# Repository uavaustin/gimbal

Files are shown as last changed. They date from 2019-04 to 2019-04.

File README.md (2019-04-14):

# gimbal
Hardware and software for UAV Austin's homebrew gimbal.

Notes:
 - MPU two jst connectors align with 7 pin header connected to STM
   - SPI connections
 - Voltage Rgulator rated for 12-13V input. Outputs 3.3V up to 250 mA
 - CP2102 USB to UART converter
 - Boot0 and Boot1 in 3 and 4 pin arrangement for programming settings
   - Boot0 connects to either ground or PWR (3.3V)
   - Boot1  (PB2) connects to ground, PWR, or the motor controller
 - MPU goes on its own board seperate from the STM, DRV, CP2102, USB, and Voltage Regulator
 - Jumper to connect NRST to ground or external input voltage
 - PA13/14 jtag | PB4/5/6/7 SPI on STM
 - 2 sets of 2 header pins to get power from battery

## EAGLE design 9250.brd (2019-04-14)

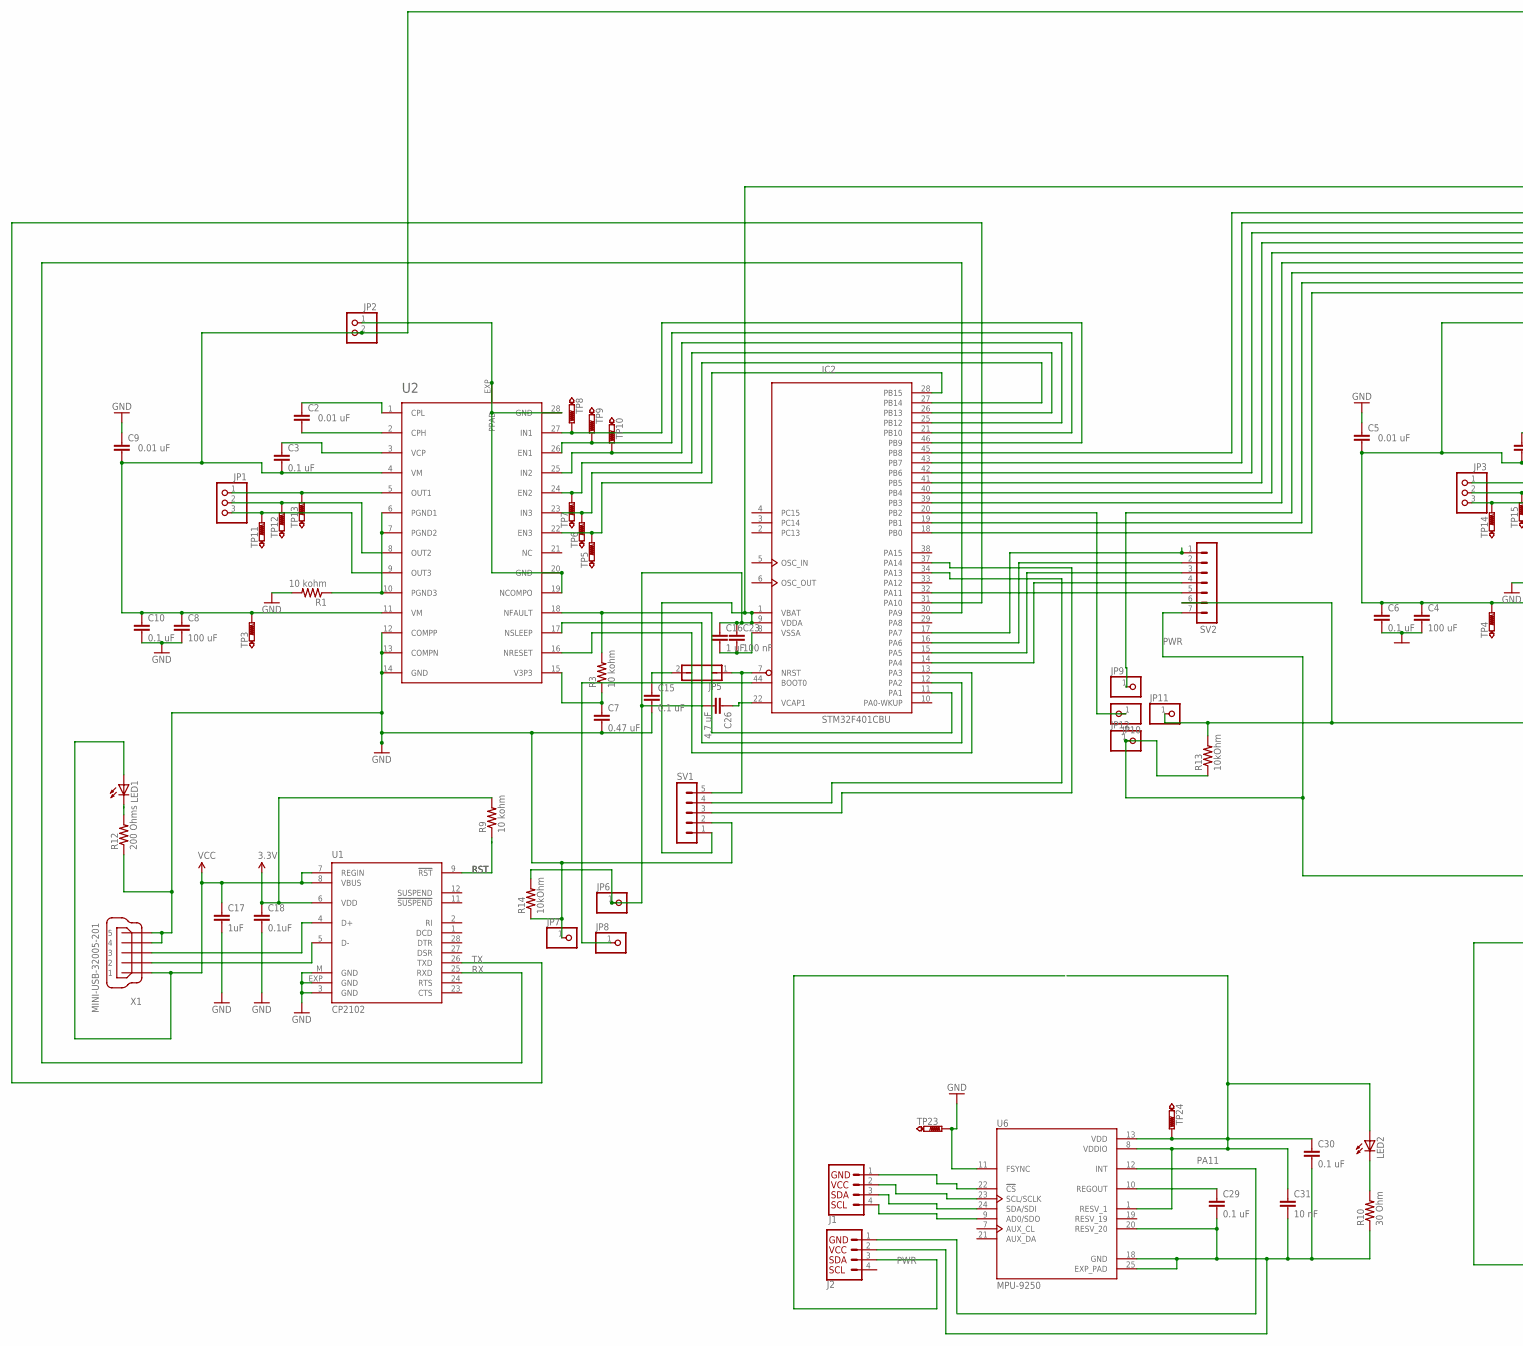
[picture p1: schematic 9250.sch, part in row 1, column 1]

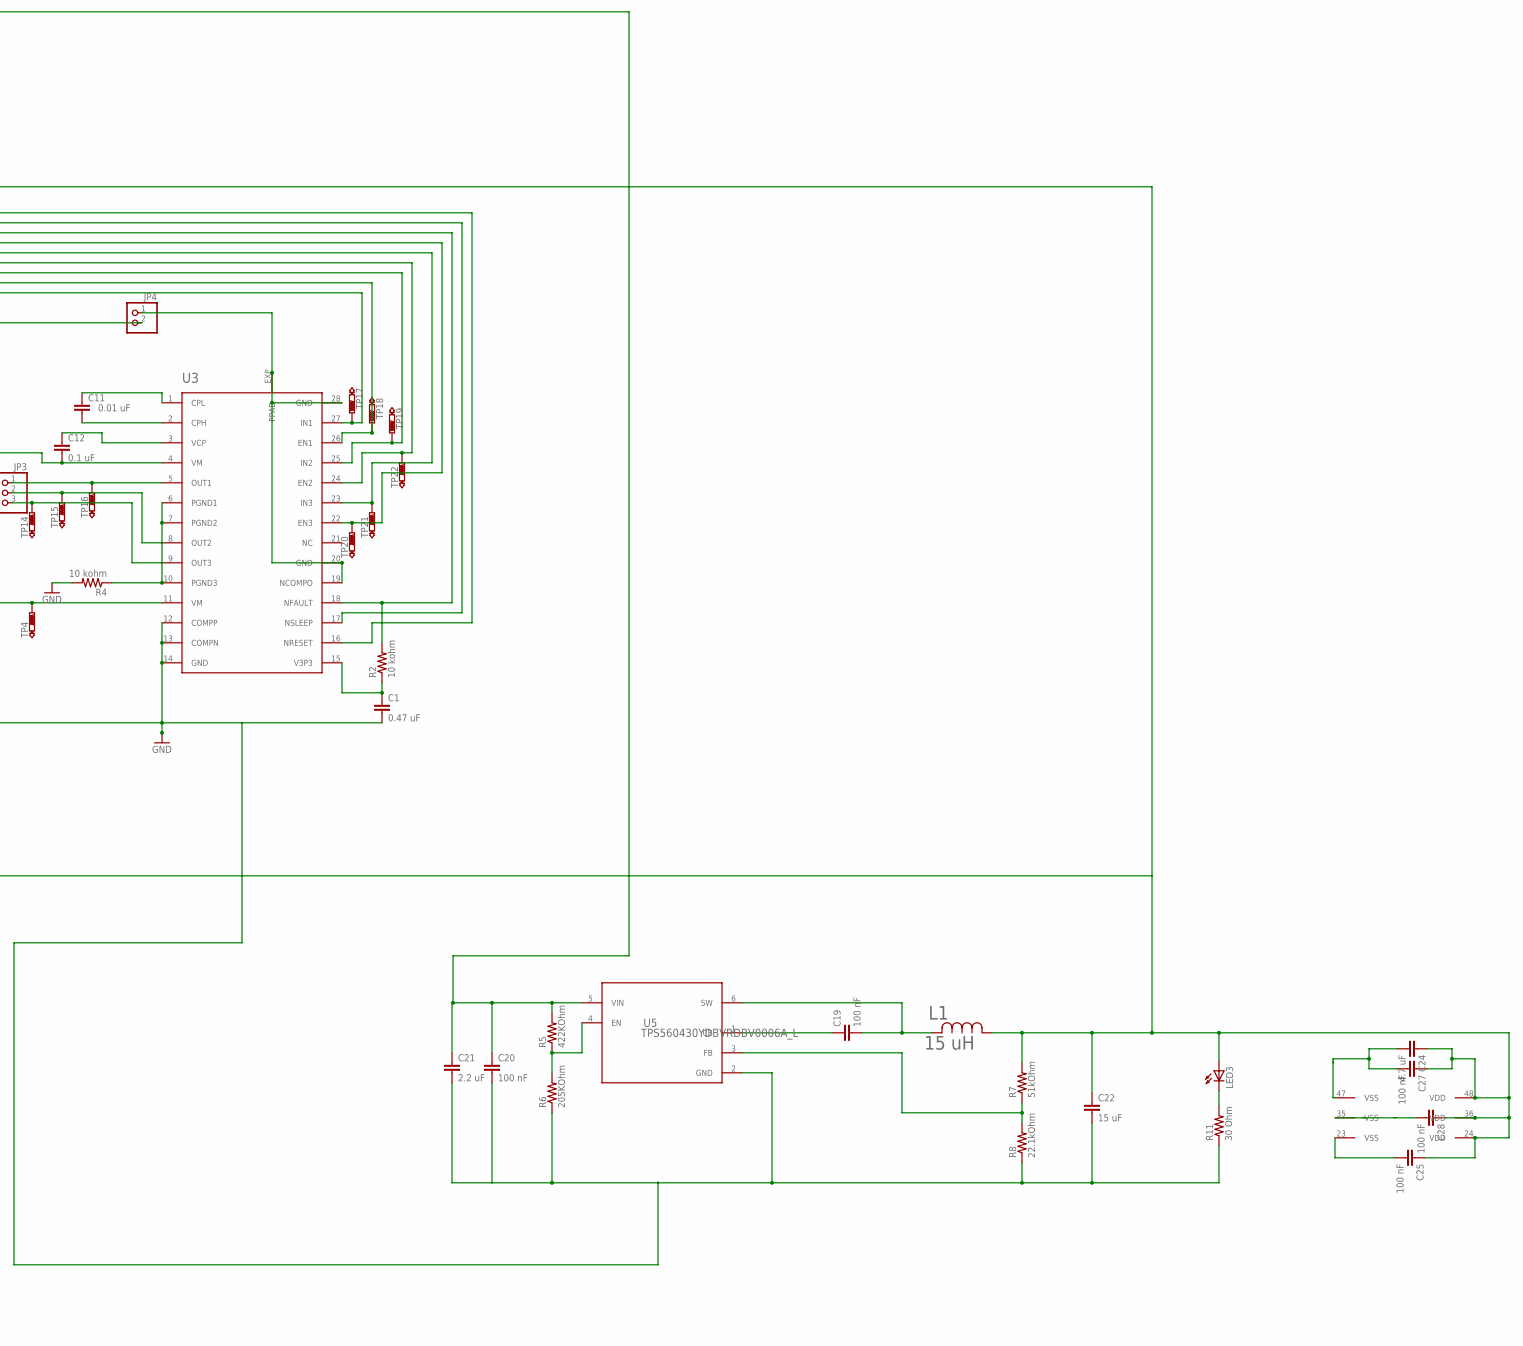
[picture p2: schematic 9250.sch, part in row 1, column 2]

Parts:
C1, C7: 0.47 uF; C1210K
C2, C5, C9, C11: 0.01 uF; C1210K
C3, C6, C10, C12, C15: 0.1 uF; C1210K
C4, C8: 100 uF; C1210K
C16: 1 uF; C1210K
C17: 1uF; 0603
C18: 0.1uF; 0603
C19, C20: 100 nF; C0402K
C21: 2.2 uF; C0402K
C22: 15 uF; C0402K
C23, C25, C27, C28: 100 nF; C1210K
C24, C26: 4.7 uF; C1210K
C29, C30: 0.1 uF; C025-025X050
C31: 10 nF; C025-025X050
IC2: STM32F401CBU; UFQFPN48
J1, J2: QWIIC_CONNECTORJS-1MM; 1X04_1MM_RA
JP1, JP3: PINHD-1X3/90; 1X03/90
JP2, JP4: PINHD-1X2/90; 1X02/90
JP5: JP1Q; JP1
JP6, JP7, JP8, JP9, JP10, JP11, JP12: PINHD-1X1; 1X01
L1: 15 uH; IND_BOURNS_SRN3015
LED1, LED2, LED3: LED_ESML0603; LED_SML0603
R1, R2, R3, R4, R9: 10 kohm; M2012
R5: 422KOhm; M0805
R6: 205KOhm; M0805
R7: 51kOhm; M0805
R8: 22.1kOhm; M0805
R10, R11: 30 Ohm; M0805
R12: 200 Ohms; M0805
R13, R14: 10kOhm; M0805
SV1: MA05-1
SV2: MA07-1
TP3, TP4, TP5, TP6, TP7, TP8, TP9, TP10, TP11, TP12, TP13, TP14, TP15, TP16, TP17, TP18, TP19, TP20, TP21, TP22, TP23, TP24: PTR1TP12R; TP12R
U1: CP2102; MLP28
U2, U3: DRV8313PWPR; HTSSOP28PWP
U5: TPS560430YDBVRDBV0006A_L; DBV0006A_L
U6: MPU-9250; QFN40P300X300X105-25N
X1: MINI-USB-32005-201; 32005-201

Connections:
3.3V: C18.1, R9.2, U1.6 (VDD)
BATTERY: C3.2, C8.1, C9.2, C10.1, C20.1, C21.1, JP2.2, R5.2, TP3.TP, U2.4 (VM), U2.11 (VM), U5.5 (VIN)
BATTERY1: C4.1, C5.2, C6.1, C12.2, JP4.2, TP4.TP, U3.4 (VM), U3.11 (VM)
CPH: C2.2, U2.2 (CPH)
CPH1: C11.2, U3.2 (CPH)
CPL: C2.1, U2.1 (CPL)
CPL1: C11.1, U3.1 (CPL)
EN4: IC2.19 (PB1), TP18.TP, U3.26 (EN1)
EN5: IC2.39 (PB3), TP22.TP, U3.24 (EN2)
EN6: IC2.41 (PB5), TP20.TP, U3.22 (EN3)
GND: C1.2, C4.2, C5.1, C6.2, C7.2, C8.2, C9.1, C10.2, C15.2, C17.2, C18.2, JP2.1, JP4.1, JP7.1, JP11.1, R1.2, R4.2, R12.1, R13.2, R14.1, SV1.2, SV2.6, TP23.TP, U1.3 (GND), U1.EXP (GND), U1.M (GND), U2.12 (COMPP), U2.13 (COMPN), U2.14 (GND), U2.19 (NCOMPO), U2.20 (GND), U2.28 (GND), U2.EXP (PPAD), U3.12 (COMPP), U3.13 (COMPN), U3.14 (GND), U3.19 (NCOMPO), U3.20 (GND), U3.28 (GND), U3.EXP (PPAD), U6.11 (FSYNC), X1.4, X1.5
IN4: IC2.18 (PB0), TP17.TP, U3.27 (IN1)
IN5: JP9.1, TP19.TP, U3.25 (IN2)
IN6: IC2.40 (PB4), TP21.TP, U3.23 (IN3)
unnamed: IC2.32 (PA11), SV2.5
unnamed: IC2.46 (PB9), TP8.TP, U2.27 (IN1)
unnamed: IC2.21 (PB10), TP9.TP, U2.26 (EN1)
unnamed: C15.1, JP5.2
unnamed: C29.1, U6.10 (REGOUT)
unnamed: IC2.30 (PA9), U1.25 (RXD)
unnamed: IC2.31 (PA10), U1.26 (TXD)
unnamed: IC2.17 (PA7), SV2.1
unnamed: C26.1, IC2.22 (VCAP1)
unnamed: IC2.14 (PA4), SV2.4
unnamed: IC2.25 (PB12), TP10.TP, U2.25 (IN2)
unnamed: C30.1, C31.1, LED2.A, TP24.TP, U6.1 (RESV_1), U6.8 (VDDIO), U6.13 (VDD)
unnamed: IC2.26 (PB13), TP7.TP, U2.24 (EN2)
unnamed: IC2.27 (PB14), TP6.TP, U2.23 (IN3)
unnamed: IC2.28 (PB15), TP5.TP, U2.22 (EN3)
unnamed: IC2.7 (NRST), JP5.1, SV1.5
unnamed: C20.2, C21.2, C22.2, R6.1, R8.1, R11.1, U5.2 (GND)
unnamed: U1.5 (D-), X1.2
unnamed: U1.4 (D+), X1.3
unnamed: IC2.44 (BOOT0), JP8.1
unnamed: C24.2, C27.2, IC2.47 (VSS)
unnamed: LED2.C, R10.2
unnamed: R5.1, R6.2, U5.4 (EN)
unnamed: C19.1, U5.1 (CB)
unnamed: C19.2, L1.2, U5.6 (SW)
unnamed: C25.2, IC2.23 (VSS)
unnamed: R7.1, R8.2, U5.3 (FB)
unnamed: C28.2, IC2.35 (VSS)
unnamed: C16.2, C23.2, IC2.8 (VSSA)
unnamed: C29.2, C30.2, C31.2, J2.2, R10.1, U6.18 (GND), U6.20 (RESV_20), U6.25 (EXP_PAD)
unnamed: LED3.C, R11.2
unnamed: LED1.C, R12.2
unnamed: IC2.15 (PA5), SV2.3
unnamed: IC2.16 (PA6), SV2.2
unnamed: IC2.20 (PB2), JP10.1
NFAULT: IC2.11 (PA1), R3.2, U2.18 (NFAULT)
NFAULT1: IC2.42 (PB6), R2.2, U3.18 (NFAULT)
NRESET: IC2.13 (PA3), U2.16 (NRESET)
NRESET1: IC2.45 (PB8), U3.16 (NRESET)
NSLEEP: IC2.12 (PA2), U2.17 (NSLEEP)
NSLEEP1: IC2.43 (PB7), U3.17 (NSLEEP)
OUT1: JP1.1, TP13.TP, U2.5 (OUT1)
OUT2: JP1.2, TP12.TP, U2.8 (OUT2)
OUT3: JP1.3, TP11.TP, U2.9 (OUT3)
OUT4: JP3.1, TP16.TP, U3.5 (OUT1)
OUT5: JP3.2, TP15.TP, U3.8 (OUT2)
OUT6: JP3.3, TP14.TP, U3.9 (OUT3)
PA11: U6.12 (INT)
PA12: J1.4, U6.9 (AD0/SDO)
PA13: J1.3, U6.24 (SDA/SDI)
PA14: J1.2, U6.23 (SCL/SCLK)
PA15: J1.1, U6.22 (!CS)
PGND: R1.1, U2.6 (PGND1), U2.7 (PGND2), U2.10 (PGND3)
PGND1: R4.1, U3.6 (PGND1), U3.7 (PGND2), U3.10 (PGND3)
PWR: C16.1, C22.1, C23.1, C24.1, C25.1, C26.2, C27.1, C28.1, IC2.1 (VBAT), IC2.9 (VDDA), IC2.24 (VDD), IC2.36 (VDD), IC2.48 (VDD), J2.3, JP6.1, JP12.1, L1.1, LED3.A, R7.2, R13.1, R14.2, SV1.1, SV2.7
RST: R9.1, U1.9 (!RST)
RX: IC2.34 (PA13), SV1.4
TX: IC2.37 (PA14), SV1.3
V3P1: C1.1, R2.1, U3.15 (V3P3)
V3P3: C7.1, R3.1, U2.15 (V3P3)
VCC: C17.1, LED1.A, U1.7 (REGIN), U1.8 (VBUS), X1.1
VCP: C3.1, U2.3 (VCP)
VCP1: C12.1, U3.3 (VCP)

Board: 2 copper layers, 92 parts (0 on the bottom side), 76 nets, no tracks yet.

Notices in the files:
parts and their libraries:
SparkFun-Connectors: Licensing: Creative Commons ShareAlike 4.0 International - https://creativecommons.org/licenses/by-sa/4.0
